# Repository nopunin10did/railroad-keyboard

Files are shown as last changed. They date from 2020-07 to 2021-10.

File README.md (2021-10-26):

# The Railroad Keyboard
PCB and Plate Repository

The Railroad

A long keyboard with ortholinear alphas and semi-standard modifier keys. For more information, join the [NoPunIn10Key Discord](https://discord.gg/7AcdaNw5Fn).

* Keyboard Maintainer: [NoPunIn10Did](https://nopunin10did.com)
* Hardware Supported: The Railroad: 2020-07 Prototype

This repository contains the KiCad files for the PCB, switch plate, and bottom plate. It also contains the BOM files that I used when ordering it from JLCPCB.



This work (Railroad Keyboard) is licensed under a [Creative Commons Attribution-ShareAlike 4.0 International License](https://creativecommons.org/licenses/by-sa/4.0/).

All other rights are reserved by NoPunIn10Did LLC.

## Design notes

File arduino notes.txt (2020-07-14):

Upside Down
            Col4                                            TRRS    TRRS    Row0    Row1    Row2
                                                                
            B7      Reset   +5V     GND     XTAL2   XTAL1   D0      D1      D2      D3      D5  
Col3    B3                                                                                          GND
Col2    B2                                                                                          +5V
Col1    B1                                                                                          D4  Col5
Col0    B0                                                                                          D6  Col6
        +5V                                                                                         D7  Col7
        Cap                                                                                         B4  Col8
        GND                                                                                         B5  Col9
        D+                                                                                          B6  Col10
        D-                                                                                          C6  Row3
        +5V                                                                                         C7  Row4
        E6                                                                                          E2  NONE
            VCC     GND     AREF    F0      F1      F4      F5      F6      F7      GND     VCC
                                                                                
                                    Row9    Row8    Row7    Row6    Row5    High
                                                                            Split

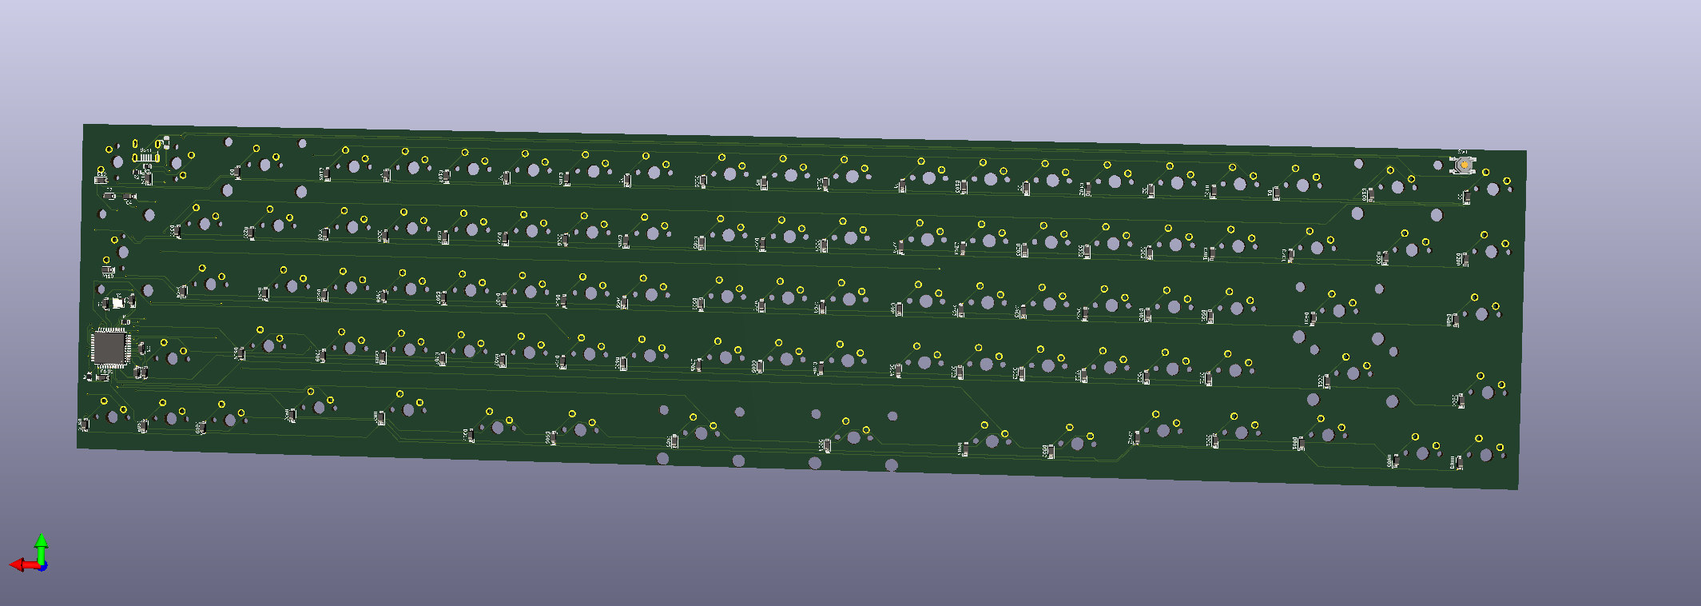
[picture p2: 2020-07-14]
images/railroad-keyboard 20200622.png

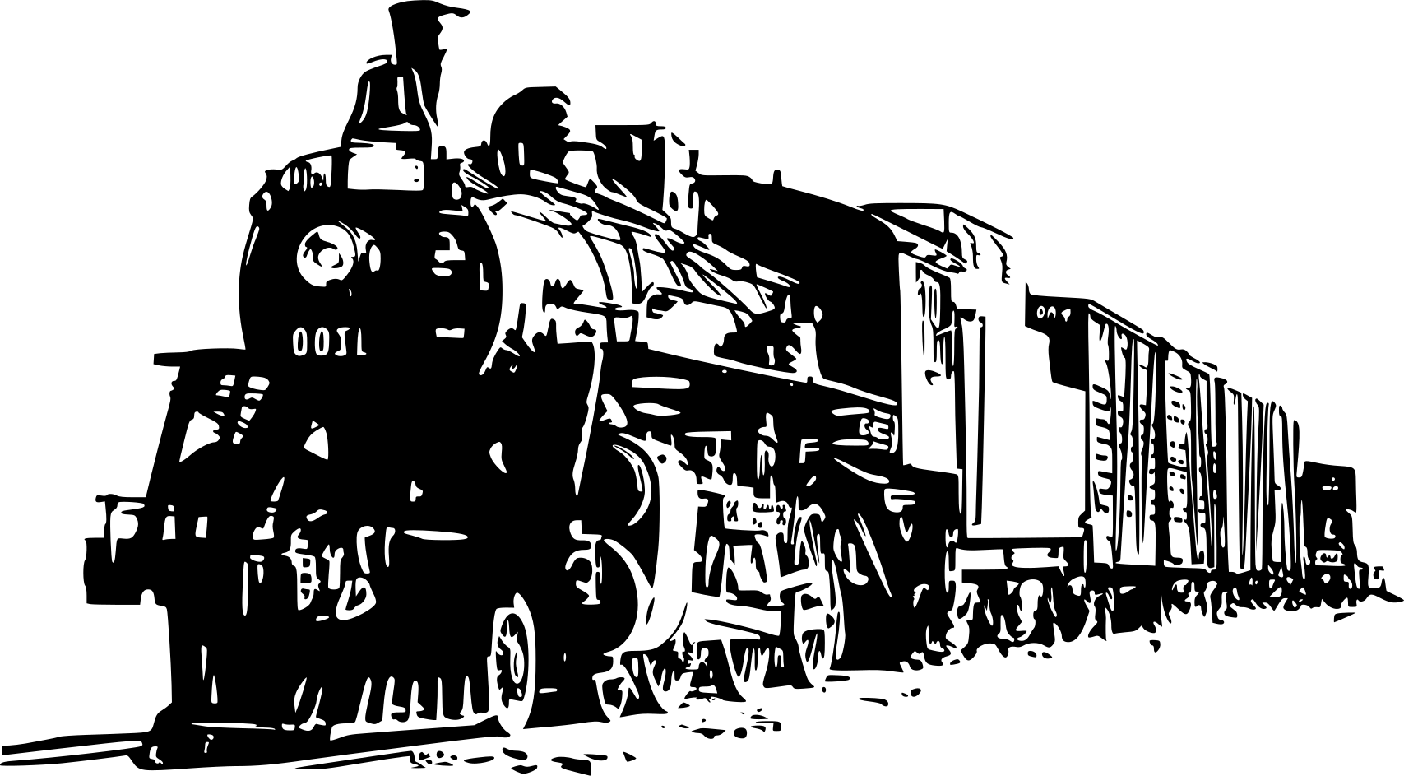
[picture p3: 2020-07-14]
images/public-domain-train.png

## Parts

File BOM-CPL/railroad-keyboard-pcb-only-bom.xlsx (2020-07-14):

Comment | Designator | Footprint | LCSC Part Number
16MHz | Y1 | 3225 | C13738
ATmega32U4-AU | U1 | 44-TQFP (10x10) | C44854
4.7k | R7, R8 | 0805 | C17673
10k | R1, R4, R6 | 0805 | C17414
1m | R5 | 0805 | C17514
22 | R2, R3 | 0805 | C17561
500mA | F1 | 1206 | C151162
SOD-123 | D0-909 | SOD-123 | C81598
22pF | C1, C2 | 0805 | C1804
1uF | C3 | 0805 | C28323
4.7uF | C4, C8 | 0805 | C1779
0.1uF | C5, C6, C7 | 0805 | C49678

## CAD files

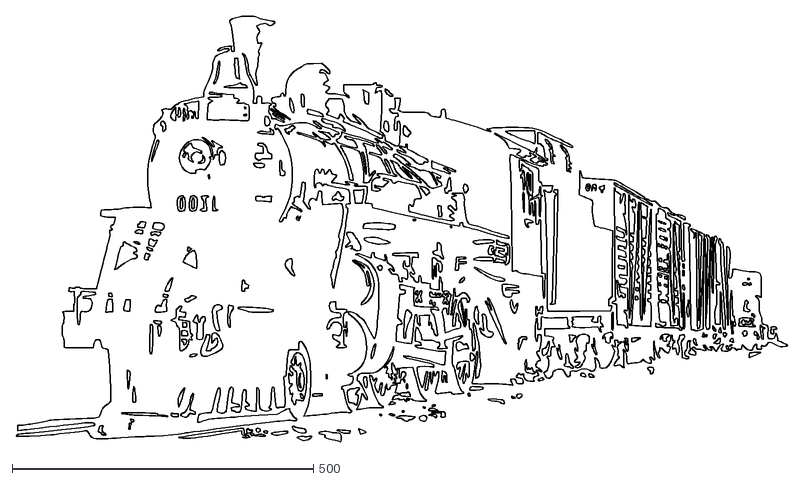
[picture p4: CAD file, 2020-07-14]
images/public-domain-train.dxf
1280.0 x 707.1

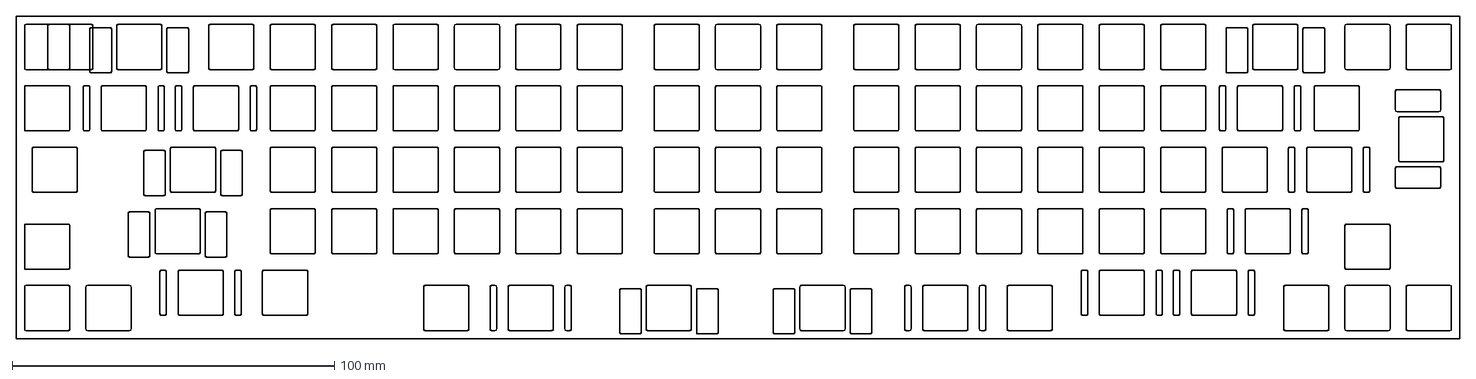
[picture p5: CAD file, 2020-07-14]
plategen/plate-20200706-135400.dxf
447.7 x 100.0 mm

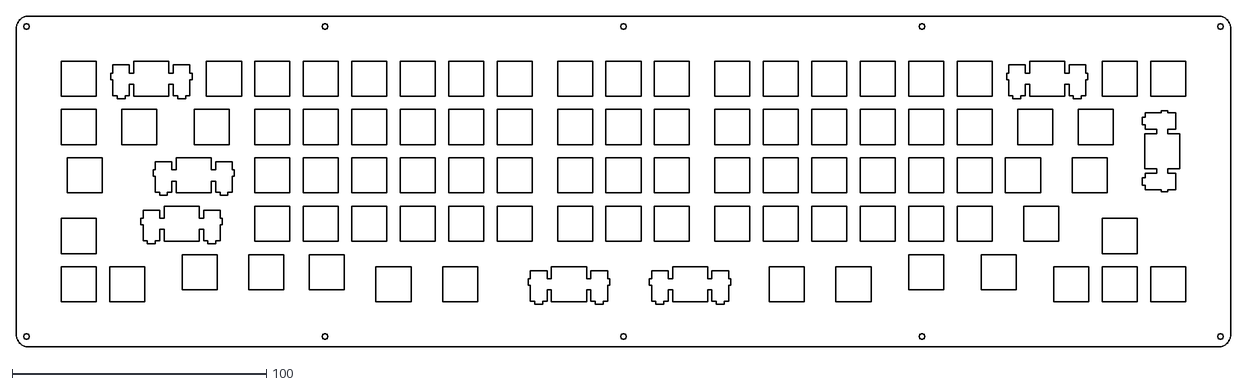
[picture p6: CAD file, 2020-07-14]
plategen/switch-plate.dxf
477.9 x 130.2

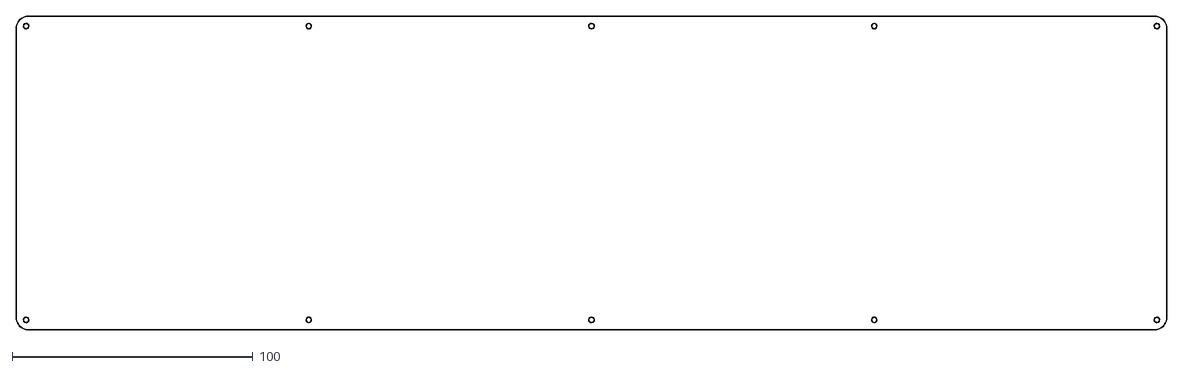
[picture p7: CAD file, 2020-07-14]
plategen/bottom-plate.dxf
477.9 x 130.2

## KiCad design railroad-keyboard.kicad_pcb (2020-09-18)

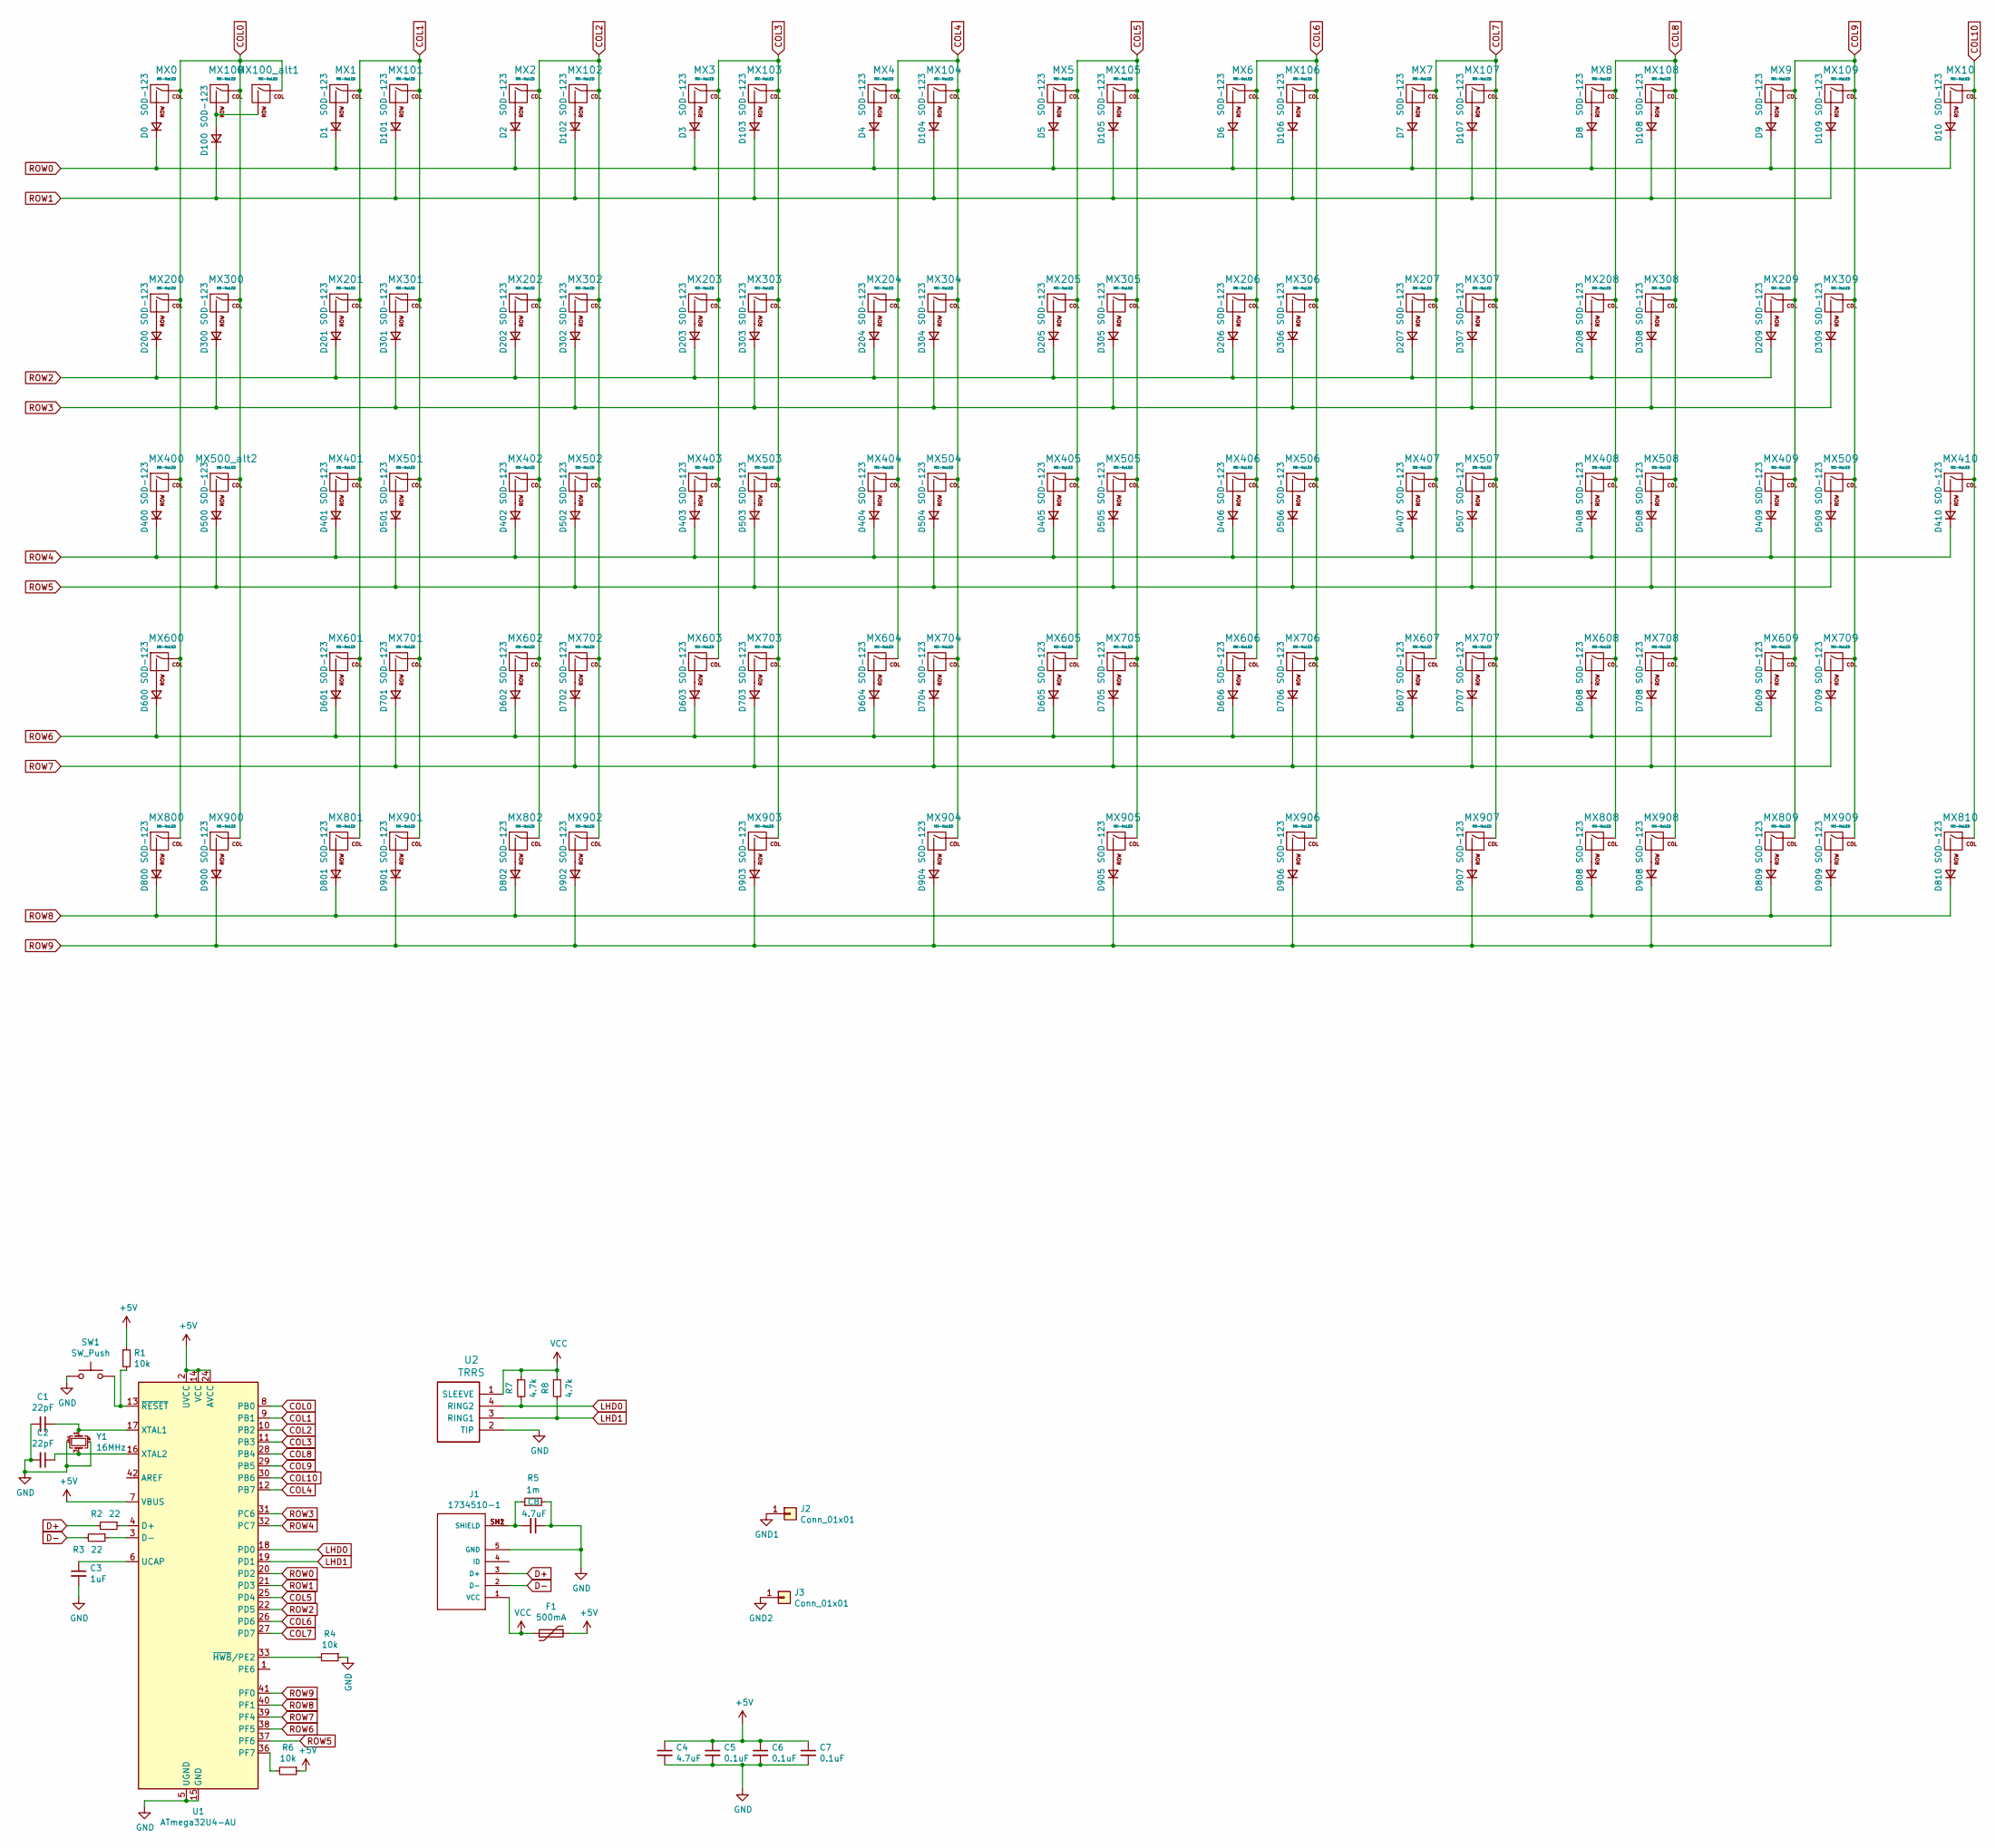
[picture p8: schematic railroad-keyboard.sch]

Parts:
C1, C2: 22pF; C_0805_2012Metric
C3: 1uF; C_0805_2012Metric
C4, C8: 4.7uF; C_0805_2012Metric
C5, C6, C7: 0.1uF; C_0805_2012Metric
D0, D1, D2, D3, D4, D5, D6, D7, D8, D9, D10, D100, D101, D102, D103, D104, D105, D106, D107, D108, D109, D200, D201, D202, D203, D204, D205, D206, D207, D208, D209, D300, D301, D302, D303, D304, D305, D306, D307, D308, D309, D400, D401, D402, D403, D404, D405, D406, D407, D408, D409, D410, D500, D501, D502, D503, D504, D505, D506, D507, D508, D509, D600, D601, D602, D603, D604, D605, D606, D607, D608, D609, D701, D702, D703, D704, D705, D706, D707, D708, D709, D800, D801, D802, D808, D809, D810, D900, D901, D902, D903, D904, D905, D906, D907, D908, D909: SOD-123; D_SOD-123
F1: 500mA; Fuse_1206_3216Metric
J1: 1734510-1; TE_1734510-1
J2, J3: Conn_01x01; PinHeader_1x01_P1.00mm_Horizontal
MX0, MX1, MX2, MX3, MX4, MX5, MX6, MX7, MX8, MX10, MX100_alt1, MX101, MX102, MX103, MX104, MX105, MX106, MX107, MX108, MX109, MX200, MX202, MX203, MX204, MX205, MX206, MX207, MX208, MX301, MX302, MX303, MX304, MX305, MX306, MX307, MX308, MX309, MX402, MX403, MX404, MX405, MX406, MX407, MX408, MX409, MX500_alt2, MX501, MX502, MX503, MX504, MX505, MX506, MX507, MX508, MX600, MX602, MX603, MX604, MX605, MX606, MX607, MX608, MX701, MX702, MX703, MX704, MX705, MX706, MX707, MX708, MX709, MX800, MX809, MX810, MX900, MX902, MX907, MX909: MX-NoLED; MXOnly-1U-NoLED
MX9, MX100: MX-NoLED; MXOnly-2U-NoLED
MX201, MX209, MX300, MX801, MX808, MX908: MX-NoLED; MXOnly-1.5U-NoLED
MX400, MX802, MX901: MX-NoLED; MXOnly-1.25U-NoLED
MX401, MX905: MX-NoLED; MXOnly-2.25U-NoLED
MX410: MX-NoLED; MXOnly-ISO-ROTATED-ReversedStabilizers-NoLED
MX509, MX609, MX903, MX906: MX-NoLED; MXOnly-1.75U-NoLED
MX601, MX904: MX-NoLED; MXOnly-2.75U-NoLED
R1, R4, R6: 10k; R_0805_2012Metric
R2, R3: 22; R_0805_2012Metric
R5: 1m; R_0805_2012Metric
R7, R8: 4.7k; R_0805_2012Metric
SW1: SW_Push; SW_Tactile_SPST_Angled_MJTP1117
U1: ATmega32U4-AU; TQFP-44_10x10mm_P0.8mm
U2: TRRS; TRRS-PJ-320A
Y1: 16MHz; Crystal_SMD_3225-4Pin_3.2x2.5mm

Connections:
+5V: C4.1, C5.1, C6.1, C7.1, F1.1, R1.1, R6.1, U1.2 (UVCC), U1.7 (VBUS), U1.14 (VCC), U1.24 (AVCC), U1.34 (VCC), U1.44 (AVCC)
COL0: MX0.1 (COL), MX100.1 (COL), MX100_alt1.1 (COL), MX200.1 (COL), MX300.1 (COL), MX400.1 (COL), MX500_alt2.1 (COL), MX600.1 (COL), MX800.1 (COL), MX900.1 (COL), U1.8 (PB0)
COL1: MX1.1 (COL), MX101.1 (COL), MX201.1 (COL), MX301.1 (COL), MX401.1 (COL), MX501.1 (COL), MX601.1 (COL), MX701.1 (COL), MX801.1 (COL), MX901.1 (COL), U1.9 (PB1)
COL2: MX2.1 (COL), MX102.1 (COL), MX202.1 (COL), MX302.1 (COL), MX402.1 (COL), MX502.1 (COL), MX602.1 (COL), MX702.1 (COL), MX802.1 (COL), MX902.1 (COL), U1.10 (PB2)
COL3: MX3.1 (COL), MX103.1 (COL), MX203.1 (COL), MX303.1 (COL), MX403.1 (COL), MX503.1 (COL), MX603.1 (COL), MX703.1 (COL), MX903.1 (COL), U1.11 (PB3)
COL4: MX4.1 (COL), MX104.1 (COL), MX204.1 (COL), MX304.1 (COL), MX404.1 (COL), MX504.1 (COL), MX604.1 (COL), MX704.1 (COL), MX904.1 (COL), U1.12 (PB7)
COL5: MX5.1 (COL), MX105.1 (COL), MX205.1 (COL), MX305.1 (COL), MX405.1 (COL), MX505.1 (COL), MX605.1 (COL), MX705.1 (COL), MX905.1 (COL), U1.25 (PD4)
COL6: MX6.1 (COL), MX106.1 (COL), MX206.1 (COL), MX306.1 (COL), MX406.1 (COL), MX506.1 (COL), MX606.1 (COL), MX706.1 (COL), MX906.1 (COL), U1.26 (PD6)
COL7: MX7.1 (COL), MX107.1 (COL), MX207.1 (COL), MX307.1 (COL), MX407.1 (COL), MX507.1 (COL), MX607.1 (COL), MX707.1 (COL), MX907.1 (COL), U1.27 (PD7)
COL8: MX8.1 (COL), MX108.1 (COL), MX208.1 (COL), MX308.1 (COL), MX408.1 (COL), MX508.1 (COL), MX608.1 (COL), MX708.1 (COL), MX808.1 (COL), MX908.1 (COL), U1.28 (PB4)
COL9: MX9.1 (COL), MX109.1 (COL), MX209.1 (COL), MX309.1 (COL), MX409.1 (COL), MX509.1 (COL), MX609.1 (COL), MX709.1 (COL), MX809.1 (COL), MX909.1 (COL), U1.29 (PB5)
COL10: MX10.1 (COL), MX410.1 (COL), MX810.1 (COL), U1.30 (PB6)
D+: J1.3 (D+), R2.2
D-: J1.2 (D-), R3.2
GND: C1.2, C2.2, C3.2, C4.2, C5.2, C6.2, C7.2, C8.1, J1.5 (GND), R4.1, R5.2, SW1.1, U1.5 (UGND), U1.15 (GND), U1.23 (GND), U1.35 (GND), U1.43 (GND), U2.2 (TIP), Y1.2, Y1.4
GND1: J2.1
GND2: J3.1
LHD0: R7.2, U1.18 (PD0), U2.4 (RING2)
LHD1: R8.2, U1.19 (PD1), U2.3 (RING1)
unnamed: C1.1, U1.17 (XTAL1), Y1.1
unnamed: C2.1, U1.16 (XTAL2), Y1.3
unnamed: C3.1, U1.6 (UCAP)
unnamed: C8.2, J1.SH1 (SHIELD), J1.SH2 (SHIELD), R5.1
unnamed: D0.2 (A), MX0.2 (ROW)
unnamed: D1.2 (A), MX1.2 (ROW)
unnamed: D2.2 (A), MX2.2 (ROW)
unnamed: D3.2 (A), MX3.2 (ROW)
unnamed: D4.2 (A), MX4.2 (ROW)
unnamed: D5.2 (A), MX5.2 (ROW)
unnamed: D6.2 (A), MX6.2 (ROW)
unnamed: D7.2 (A), MX7.2 (ROW)
unnamed: D8.2 (A), MX8.2 (ROW)
unnamed: D9.2 (A), MX9.2 (ROW)
unnamed: D10.2 (A), MX10.2 (ROW)
unnamed: D100.2 (A), MX100.2 (ROW), MX100_alt1.2 (ROW)
unnamed: D101.2 (A), MX101.2 (ROW)
unnamed: D102.2 (A), MX102.2 (ROW)
unnamed: D103.2 (A), MX103.2 (ROW)
unnamed: D104.2 (A), MX104.2 (ROW)
unnamed: D105.2 (A), MX105.2 (ROW)
unnamed: D106.2 (A), MX106.2 (ROW)
unnamed: D107.2 (A), MX107.2 (ROW)
unnamed: D108.2 (A), MX108.2 (ROW)
unnamed: D109.2 (A), MX109.2 (ROW)
unnamed: D200.2 (A), MX200.2 (ROW)
unnamed: D201.2 (A), MX201.2 (ROW)
unnamed: D202.2 (A), MX202.2 (ROW)
unnamed: D203.2 (A), MX203.2 (ROW)
unnamed: D204.2 (A), MX204.2 (ROW)
unnamed: D205.2 (A), MX205.2 (ROW)
unnamed: D206.2 (A), MX206.2 (ROW)
unnamed: D207.2 (A), MX207.2 (ROW)
unnamed: D208.2 (A), MX208.2 (ROW)
unnamed: D209.2 (A), MX209.2 (ROW)
unnamed: D300.2 (A), MX300.2 (ROW)
unnamed: D301.2 (A), MX301.2 (ROW)
unnamed: D302.2 (A), MX302.2 (ROW)
unnamed: D303.2 (A), MX303.2 (ROW)
unnamed: D304.2 (A), MX304.2 (ROW)
unnamed: D305.2 (A), MX305.2 (ROW)
unnamed: D306.2 (A), MX306.2 (ROW)
unnamed: D307.2 (A), MX307.2 (ROW)
unnamed: D308.2 (A), MX308.2 (ROW)
unnamed: D309.2 (A), MX309.2 (ROW)
unnamed: D400.2 (A), MX400.2 (ROW)
unnamed: D401.2 (A), MX401.2 (ROW)
unnamed: D402.2 (A), MX402.2 (ROW)
unnamed: D403.2 (A), MX403.2 (ROW)
unnamed: D404.2 (A), MX404.2 (ROW)
unnamed: D405.2 (A), MX405.2 (ROW)
unnamed: D406.2 (A), MX406.2 (ROW)
unnamed: D407.2 (A), MX407.2 (ROW)
unnamed: D408.2 (A), MX408.2 (ROW)
unnamed: D409.2 (A), MX409.2 (ROW)
unnamed: D410.2 (A), MX410.2 (ROW)
unnamed: D500.2 (A), MX500_alt2.2 (ROW)
unnamed: D501.2 (A), MX501.2 (ROW)
unnamed: D502.2 (A), MX502.2 (ROW)
unnamed: D503.2 (A), MX503.2 (ROW)
unnamed: D504.2 (A), MX504.2 (ROW)
unnamed: D505.2 (A), MX505.2 (ROW)
unnamed: D506.2 (A), MX506.2 (ROW)
unnamed: D507.2 (A), MX507.2 (ROW)
unnamed: D508.2 (A), MX508.2 (ROW)
unnamed: D509.2 (A), MX509.2 (ROW)
unnamed: D600.2 (A), MX600.2 (ROW)
unnamed: D601.2 (A), MX601.2 (ROW)
unnamed: D602.2 (A), MX602.2 (ROW)
unnamed: D603.2 (A), MX603.2 (ROW)
unnamed: D604.2 (A), MX604.2 (ROW)
unnamed: D605.2 (A), MX605.2 (ROW)
unnamed: D606.2 (A), MX606.2 (ROW)
unnamed: D607.2 (A), MX607.2 (ROW)
unnamed: D608.2 (A), MX608.2 (ROW)
unnamed: D609.2 (A), MX609.2 (ROW)
unnamed: D701.2 (A), MX701.2 (ROW)
unnamed: D702.2 (A), MX702.2 (ROW)
unnamed: D703.2 (A), MX703.2 (ROW)
unnamed: D704.2 (A), MX704.2 (ROW)
unnamed: D705.2 (A), MX705.2 (ROW)
unnamed: D706.2 (A), MX706.2 (ROW)
unnamed: D707.2 (A), MX707.2 (ROW)
unnamed: D708.2 (A), MX708.2 (ROW)
unnamed: D709.2 (A), MX709.2 (ROW)
unnamed: D800.2 (A), MX800.2 (ROW)
unnamed: D801.2 (A), MX801.2 (ROW)
unnamed: D802.2 (A), MX802.2 (ROW)
unnamed: D808.2 (A), MX808.2 (ROW)
unnamed: D809.2 (A), MX809.2 (ROW)
unnamed: D810.2 (A), MX810.2 (ROW)
unnamed: D900.2 (A), MX900.2 (ROW)
unnamed: D901.2 (A), MX901.2 (ROW)
unnamed: D902.2 (A), MX902.2 (ROW)
unnamed: D903.2 (A), MX903.2 (ROW)
unnamed: D904.2 (A), MX904.2 (ROW)
unnamed: D905.2 (A), MX905.2 (ROW)
unnamed: D906.2 (A), MX906.2 (ROW)
unnamed: D907.2 (A), MX907.2 (ROW)
unnamed: D908.2 (A), MX908.2 (ROW)
unnamed: D909.2 (A), MX909.2 (ROW)
unnamed: R1.2, SW1.2, U1.13 (~RESET)
unnamed: R2.1, U1.4 (D+)
unnamed: R3.1, U1.3 (D-)
unnamed: R4.2, U1.33 (~HWB~/PE2)
unnamed: R6.2, U1.36 (PF7)
ROW0: D0.1 (K), D1.1 (K), D2.1 (K), D3.1 (K), D4.1 (K), D5.1 (K), D6.1 (K), D7.1 (K), D8.1 (K), D9.1 (K), D10.1 (K), U1.20 (PD2)
ROW1: D100.1 (K), D101.1 (K), D102.1 (K), D103.1 (K), D104.1 (K), D105.1 (K), D106.1 (K), D107.1 (K), D108.1 (K), D109.1 (K), U1.21 (PD3)
ROW2: D200.1 (K), D201.1 (K), D202.1 (K), D203.1 (K), D204.1 (K), D205.1 (K), D206.1 (K), D207.1 (K), D208.1 (K), D209.1 (K), U1.22 (PD5)
ROW3: D300.1 (K), D301.1 (K), D302.1 (K), D303.1 (K), D304.1 (K), D305.1 (K), D306.1 (K), D307.1 (K), D308.1 (K), D309.1 (K), U1.31 (PC6)
ROW4: D400.1 (K), D401.1 (K), D402.1 (K), D403.1 (K), D404.1 (K), D405.1 (K), D406.1 (K), D407.1 (K), D408.1 (K), D409.1 (K), D410.1 (K), U1.32 (PC7)
ROW5: D500.1 (K), D501.1 (K), D502.1 (K), D503.1 (K), D504.1 (K), D505.1 (K), D506.1 (K), D507.1 (K), D508.1 (K), D509.1 (K), U1.37 (PF6)
ROW6: D600.1 (K), D601.1 (K), D602.1 (K), D603.1 (K), D604.1 (K), D605.1 (K), D606.1 (K), D607.1 (K), D608.1 (K), D609.1 (K), U1.38 (PF5)
ROW7: D701.1 (K), D702.1 (K), D703.1 (K), D704.1 (K), D705.1 (K), D706.1 (K), D707.1 (K), D708.1 (K), D709.1 (K), U1.39 (PF4)
ROW8: D800.1 (K), D801.1 (K), D802.1 (K), D808.1 (K), D809.1 (K), D810.1 (K), U1.40 (PF1)
ROW9: D900.1 (K), D901.1 (K), D902.1 (K), D903.1 (K), D904.1 (K), D905.1 (K), D906.1 (K), D907.1 (K), D908.1 (K), D909.1 (K), U1.41 (PF0)
VCC: F1.2, J1.1 (VCC), R7.1, R8.1, U2.1 (SLEEVE)

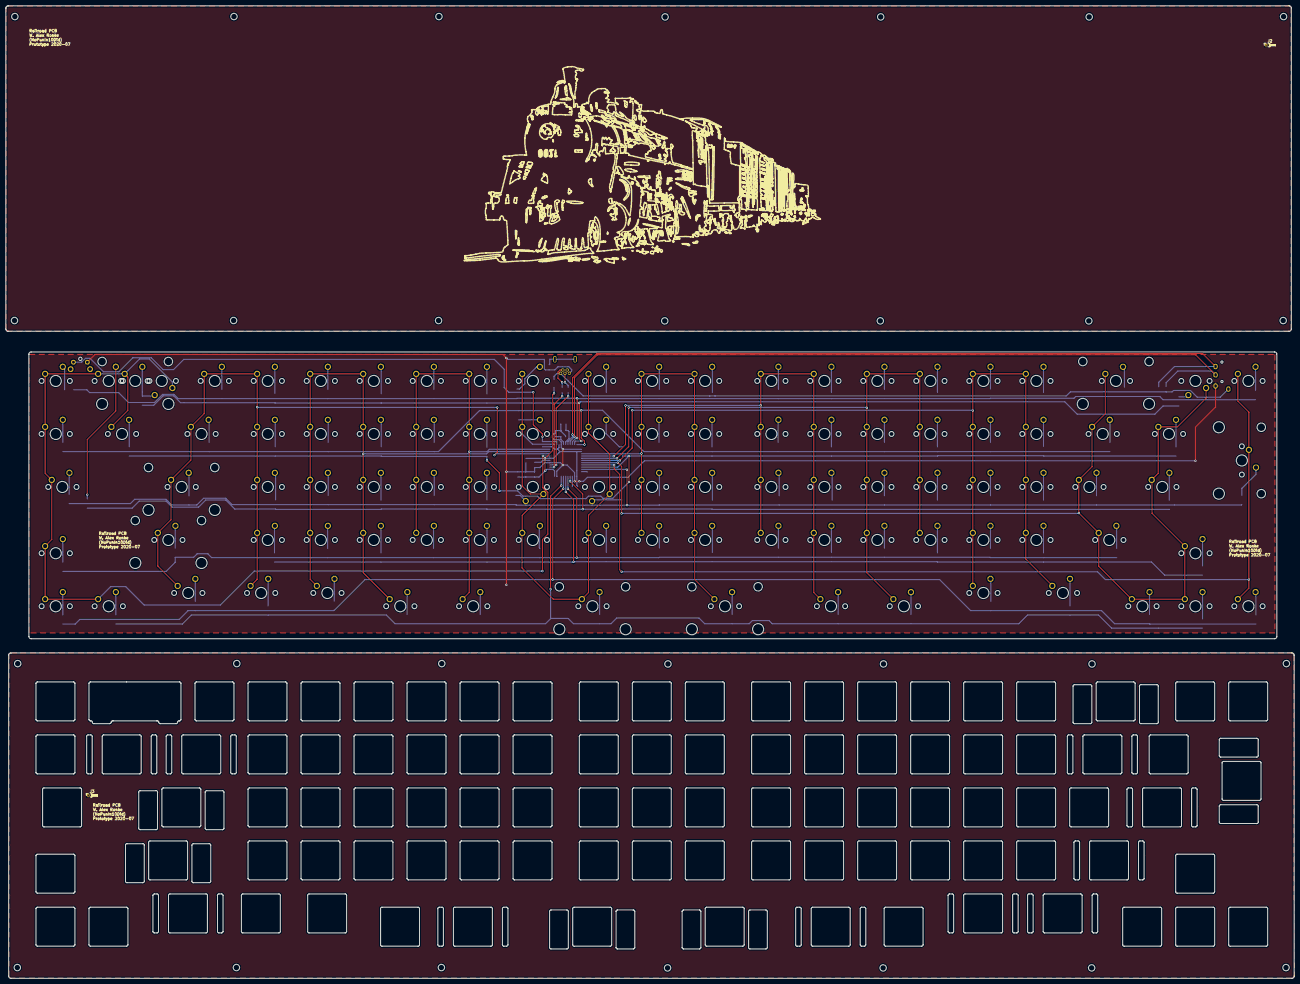
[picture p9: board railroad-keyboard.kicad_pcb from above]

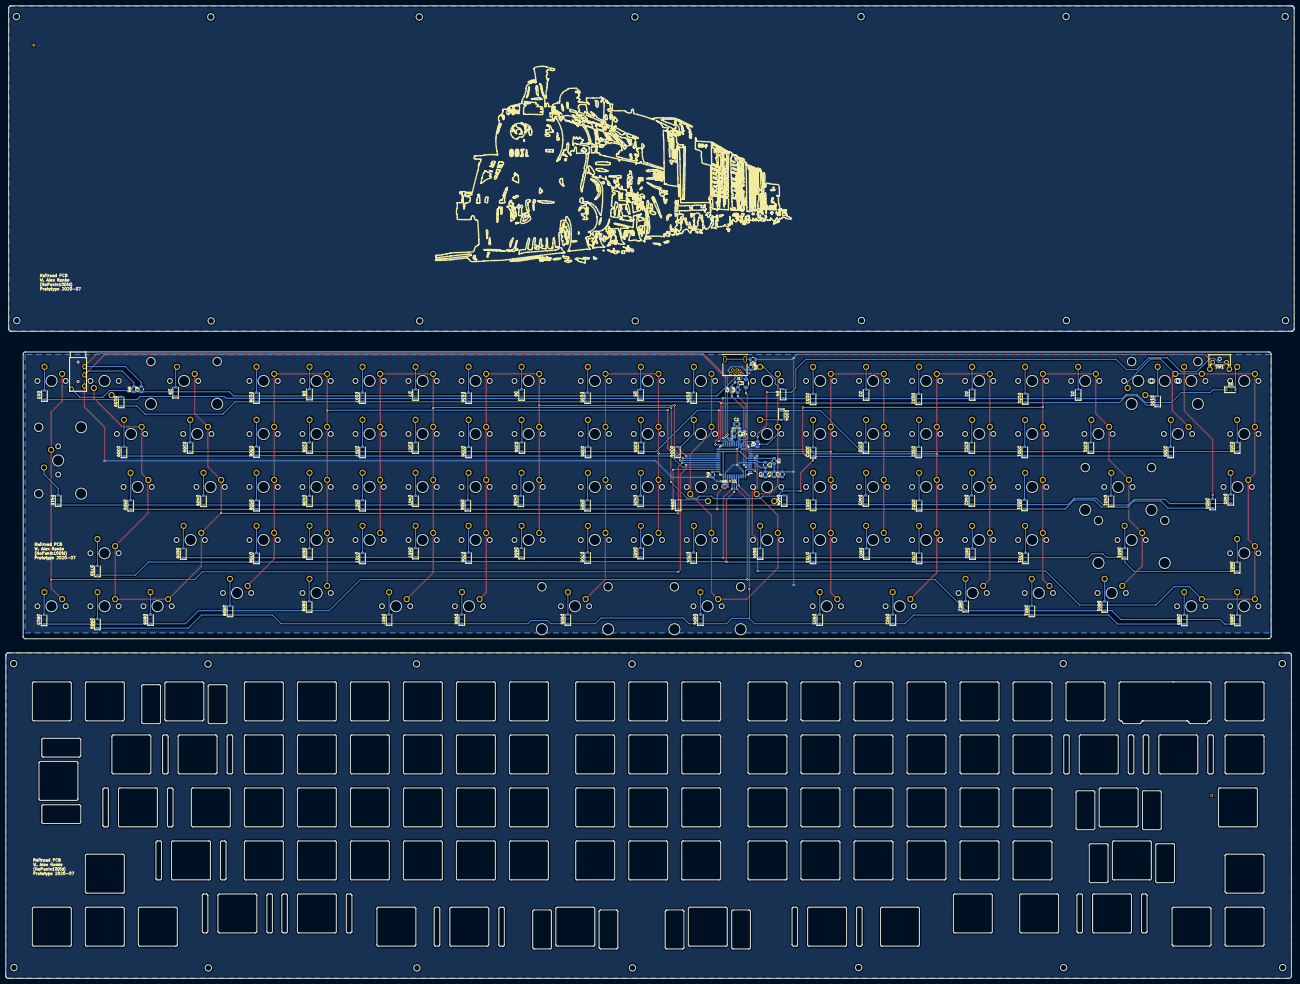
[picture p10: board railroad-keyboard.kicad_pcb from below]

Board: 2 copper layers, 448.5 x 103.0 mm, 219 parts (119 on the bottom side), 134 nets.

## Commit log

2020-06-17 Initial project file creation
    [railroad-keyboard.kicad_pcb, railroad-keyboard.sch]
2020-06-17 First full schematic draft
    [railroad-keyboard.sch]
2020-06-17 Label D and MX in schematic
    [railroad-keyboard.sch]
2020-06-19 Divide into TKL and fullsize, annotate
    [railroad-keyboard-fullsize.sch]
2020-06-20 Initial PCB org. WIP
2020-06-20 Further PCB WIP
    [railroad-keyboard.kicad_pcb]
2020-06-20 Diodes placed
    [railroad-keyboard.kicad_pcb]
2020-06-23 Completion of first draft
    [railroad-keyboard tkl-v2.kicad_pcb, railroad-keyboard-tkl-v2.sch, railroad-keyboard.kicad_pcb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]
2020-06-24 File Cleanup
    [railroad-keyboard tkl-v2.kicad_pcb, railroad-keyboard-fullsize.sch, railroad-keyboard-tkl-v2.sch]
2020-06-24 Major revisions to schema
    [railroad-keyboard.sch]
2020-06-24 Further major revisions
    [railroad-keyboard.kicad_pcb, railroad-keyboard.sch]
2020-06-24 Second tracing draft
    [railroad-keyboard.kicad_pcb]
2020-06-24 Adjustments to crystal placement
    [railroad-keyboard.kicad_pcb]
2020-07-06 Add ground fill
    [railroad-keyboard.kicad_pcb]
2020-07-06 Start reworking routing again
    [plate-20200706-135400.dxf, railroad-keyboard.kicad_pcb, railroad-keyboard.sch]
2020-07-06 Start adding plate
    [railroad-keyboard.kicad_pcb]
2020-07-07 Further progress
    [railroad-keyboard-bottom-plate-B_Cu.gbl, railroad-keyboard-bottom-plate-B_Mask.gbs, railroad-keyboard-bottom-plate-B_SilkS.gbo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]
2020-07-08 Backup prior to adding silkscreen
    [bottom-plate.dxf, public-domain-train.dxf, railroad-junction.kicad_pcb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]
2020-07-09 Just about ready to send to JLCPCB
    [railroad-keyboard-bottom-plate-B_Cu.gbl, railroad-keyboard-bottom-plate-B_Cu.gbr, railroad-keyboard-bottom-plate-B_Mask.gbr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]
2020-07-09 Needed some changes
    [railroad-keyboard-pcb-only-B_Cu.gbr, railroad-keyboard-pcb-only-B_Mask.gbr, railroad-keyboard-pcb-only-B_Paste.gbr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]
2020-07-14 Update Reset Switch and routing
    [railroad-keyboard-pcb-only-B_Cu.gbl, railroad-keyboard-pcb-only-B_Mask.gbs, railroad-keyboard-pcb-only-B_SilkS.gbo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]
2020-07-14 Submitted to JLCPCB
    [railroad-keyboard-pcb-only-bom.xlsx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]
2020-08-27 Fix missing slot in switchplate
    [railroad-keyboard-switch-plate-B_Cu.gbl, railroad-keyboard-switch-plate-B_Mask.gbr, railroad-keyboard-switch-plate-B_Mask.gbs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]
2020-09-01 Update Gerbers
    [railroad-keyboard-switch-plate-B_Cu.gbl, railroad-keyboard-switch-plate-B_Mask.gbs, railroad-keyboard-switch-plate-B_SilkS.gbo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]
2021-01-14 Update for new machine
    [railroad-keyboard.sch]
2021-10-26 Clean up old files, update license
    [railroad-junction.kicad_pcb, railroad-junction.sch]

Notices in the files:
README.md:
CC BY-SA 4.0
